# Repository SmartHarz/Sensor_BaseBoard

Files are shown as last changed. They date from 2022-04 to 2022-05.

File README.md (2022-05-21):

# Bosch Sensortec BME688 Breadboard Adapter

A simplistic sensor base board for BME688 air quality sensor by Bosch Sensortec

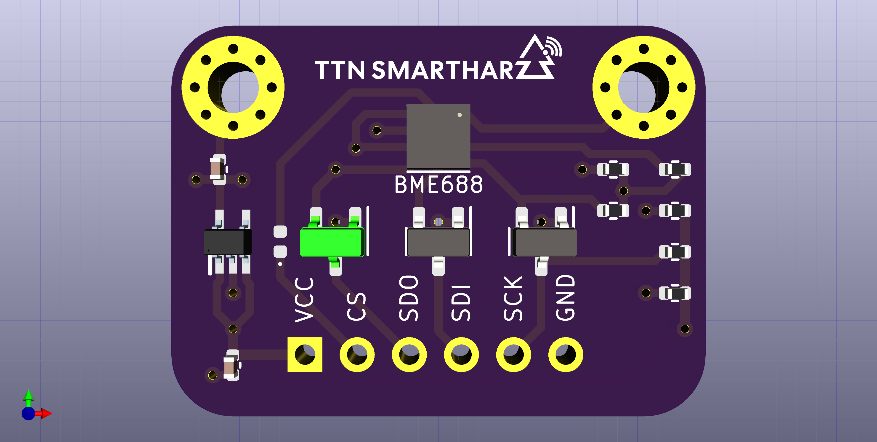
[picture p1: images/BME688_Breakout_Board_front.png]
Sensor board3D front view


The design allows for V<sub>CC</sub> and logic levels between 3V3 and 5V DC.

Due to the fact that the BME688 sensor features an LGA footprints with all pads below the sensor, manual soldering with a soldering iron is not possible for the sensor itself. All other parts can be soldered by hand, even though the 0402 components require a steady hand. Either way reflow soldering makes life a lot easier, if you keep the airflow low enough to not blow away your components. :wink:

The project folder [panel](/Sensor_BaseBoard/panel/) contains a panelized version as well
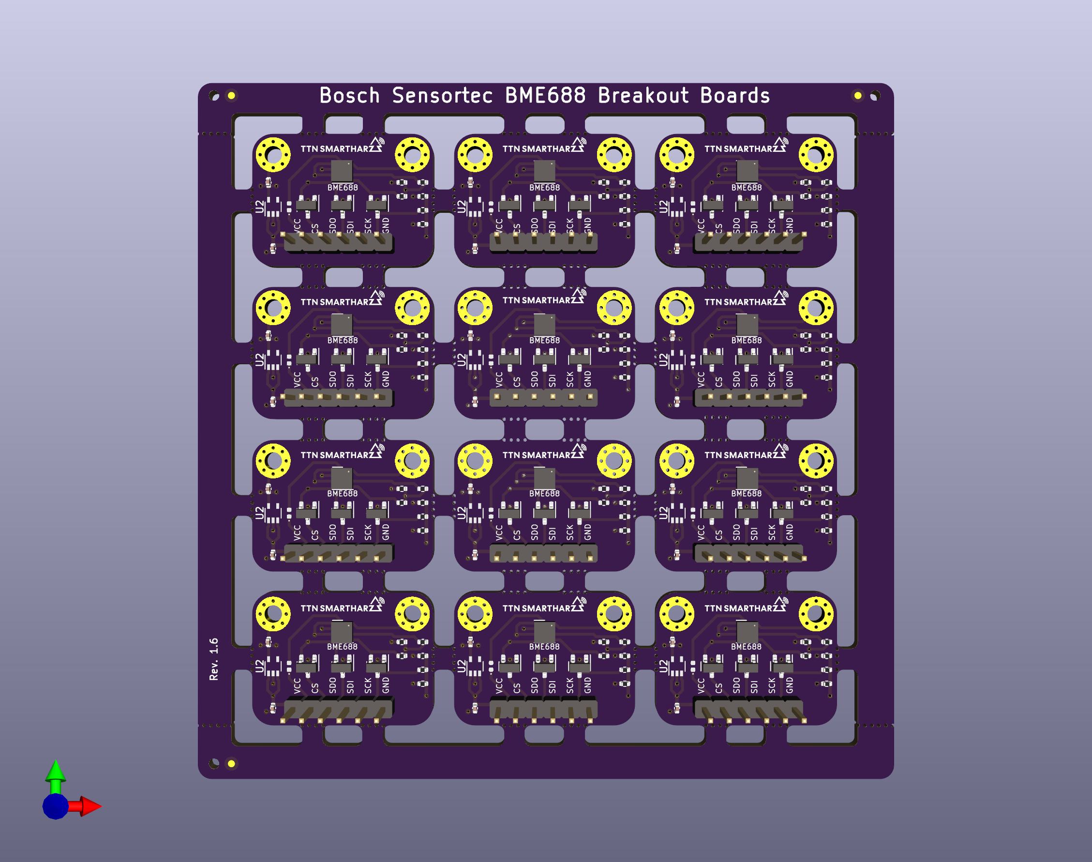
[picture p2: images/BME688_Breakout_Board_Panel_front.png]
Sensor board panel - front


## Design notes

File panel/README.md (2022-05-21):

# Bosch Sensortec BMEx80 Breadboard Adapter

This folder contains the [KiCAD](https://www.kicad.org/) project for a panelized version of the adapter.
The initial panel was generated using the kikit extension for KiCAD and afterwards cleaned up.

Panel 3D front
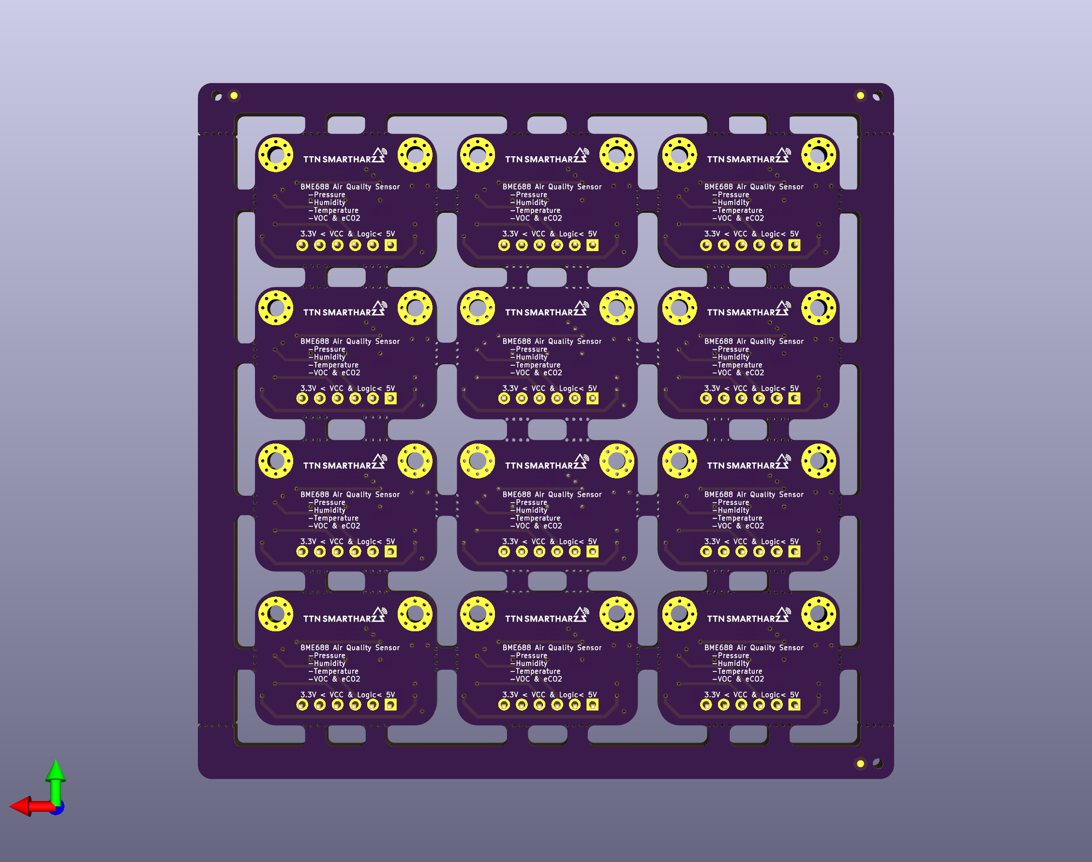
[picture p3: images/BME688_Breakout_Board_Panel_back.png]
Panel 3D back


As I prefer the look and feel I went with ENIG for manufacturing, but HASL lead free is of course perfectly fine as well.

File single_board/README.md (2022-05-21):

# Bosch Sensortec BMEx80 Breadboard Adapter

This folder contains the [KiCAD](https://www.kicad.org/) project for the single adapter.

## Schematic

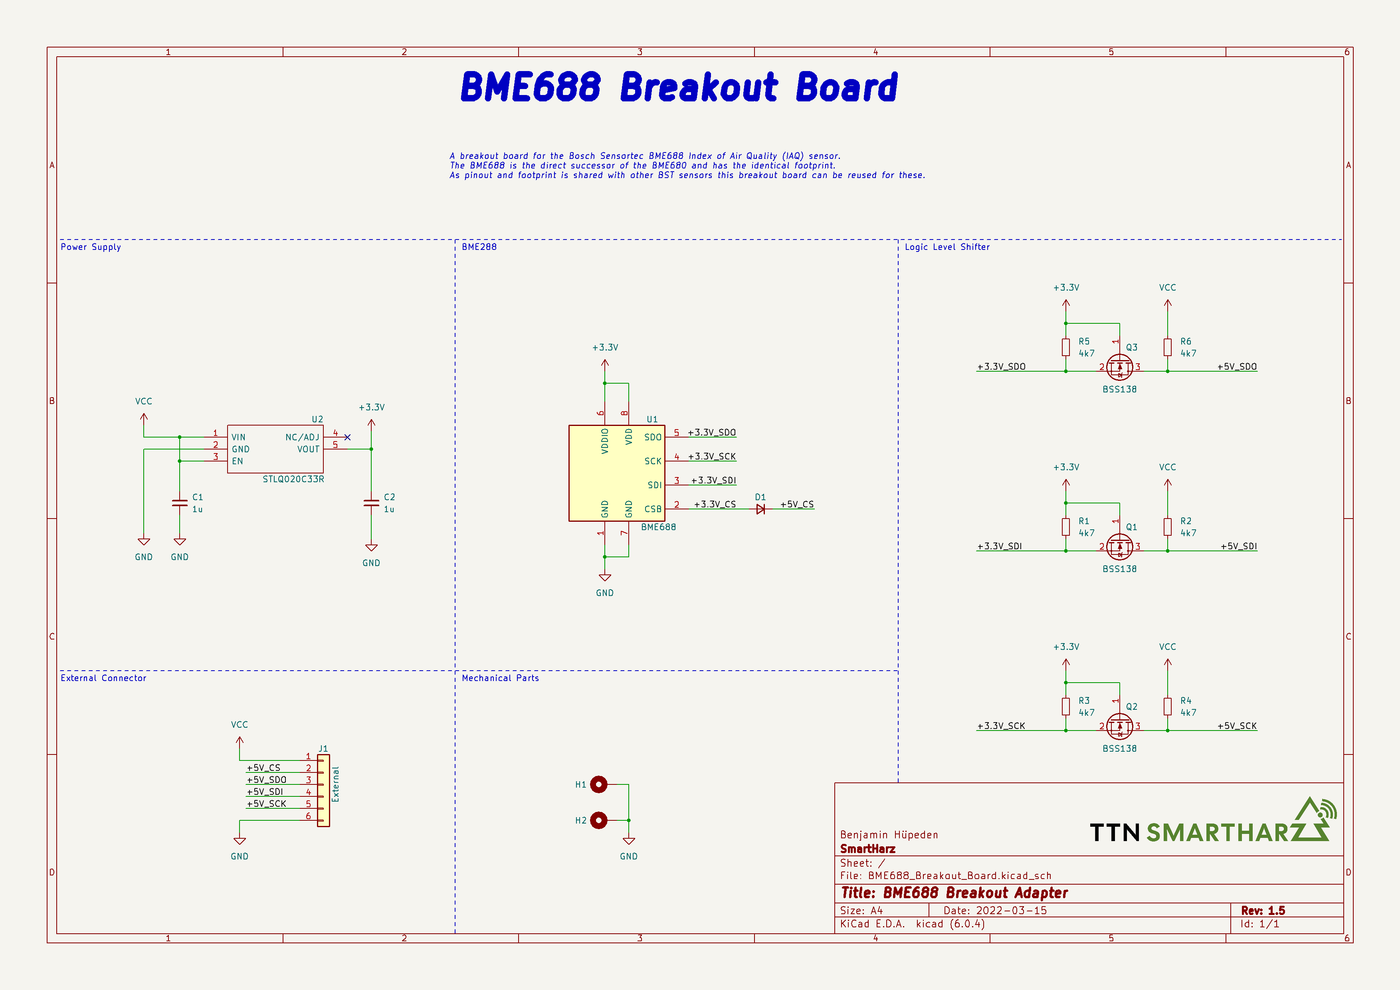
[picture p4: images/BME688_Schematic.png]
Adapter schematic

PDF of the schematic is available [here](BME688_Breakout_Board_Schematic.pdf).

## Layout

Adapter layout front
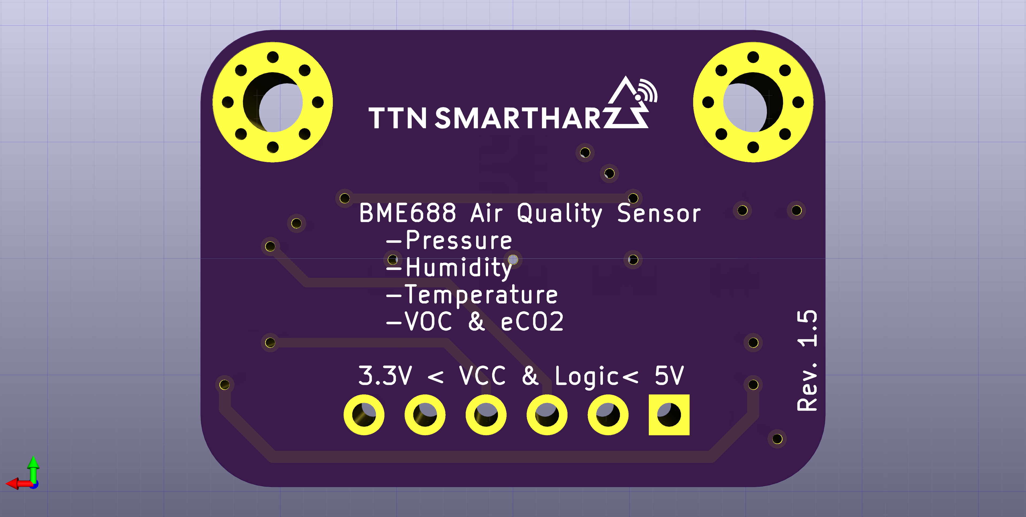
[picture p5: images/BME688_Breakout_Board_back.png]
Adapter layout back


As 4 layer boards nowadays are available at a similar price as 2 layer boards, I went for 4 layers, with dedicated GND and 3V3 planes in the middle.

A PDF of the layout is available [here](BME688_Breakout_Board_SingleLayers.pdf)(single page per layer) and [here](BME688_Breakout_Board_Condensed.pdf)(all layers condensed).

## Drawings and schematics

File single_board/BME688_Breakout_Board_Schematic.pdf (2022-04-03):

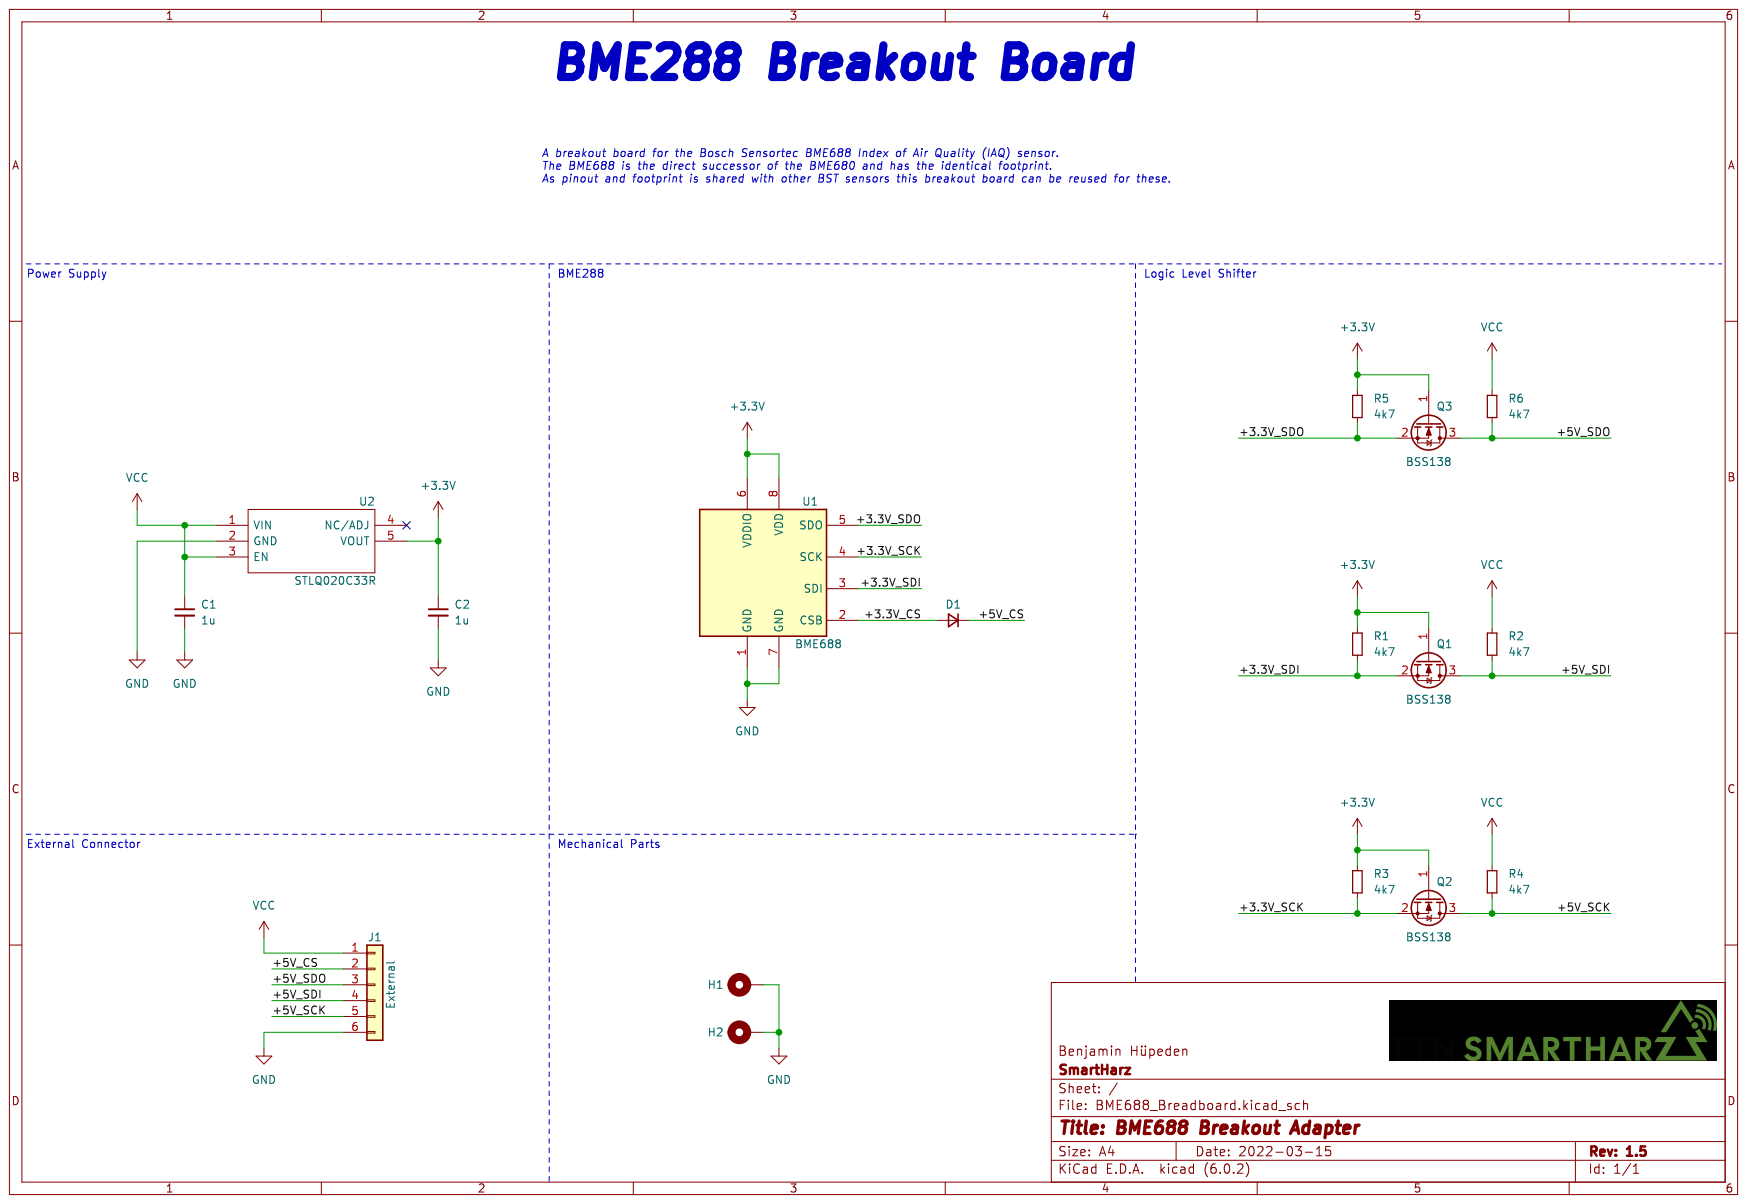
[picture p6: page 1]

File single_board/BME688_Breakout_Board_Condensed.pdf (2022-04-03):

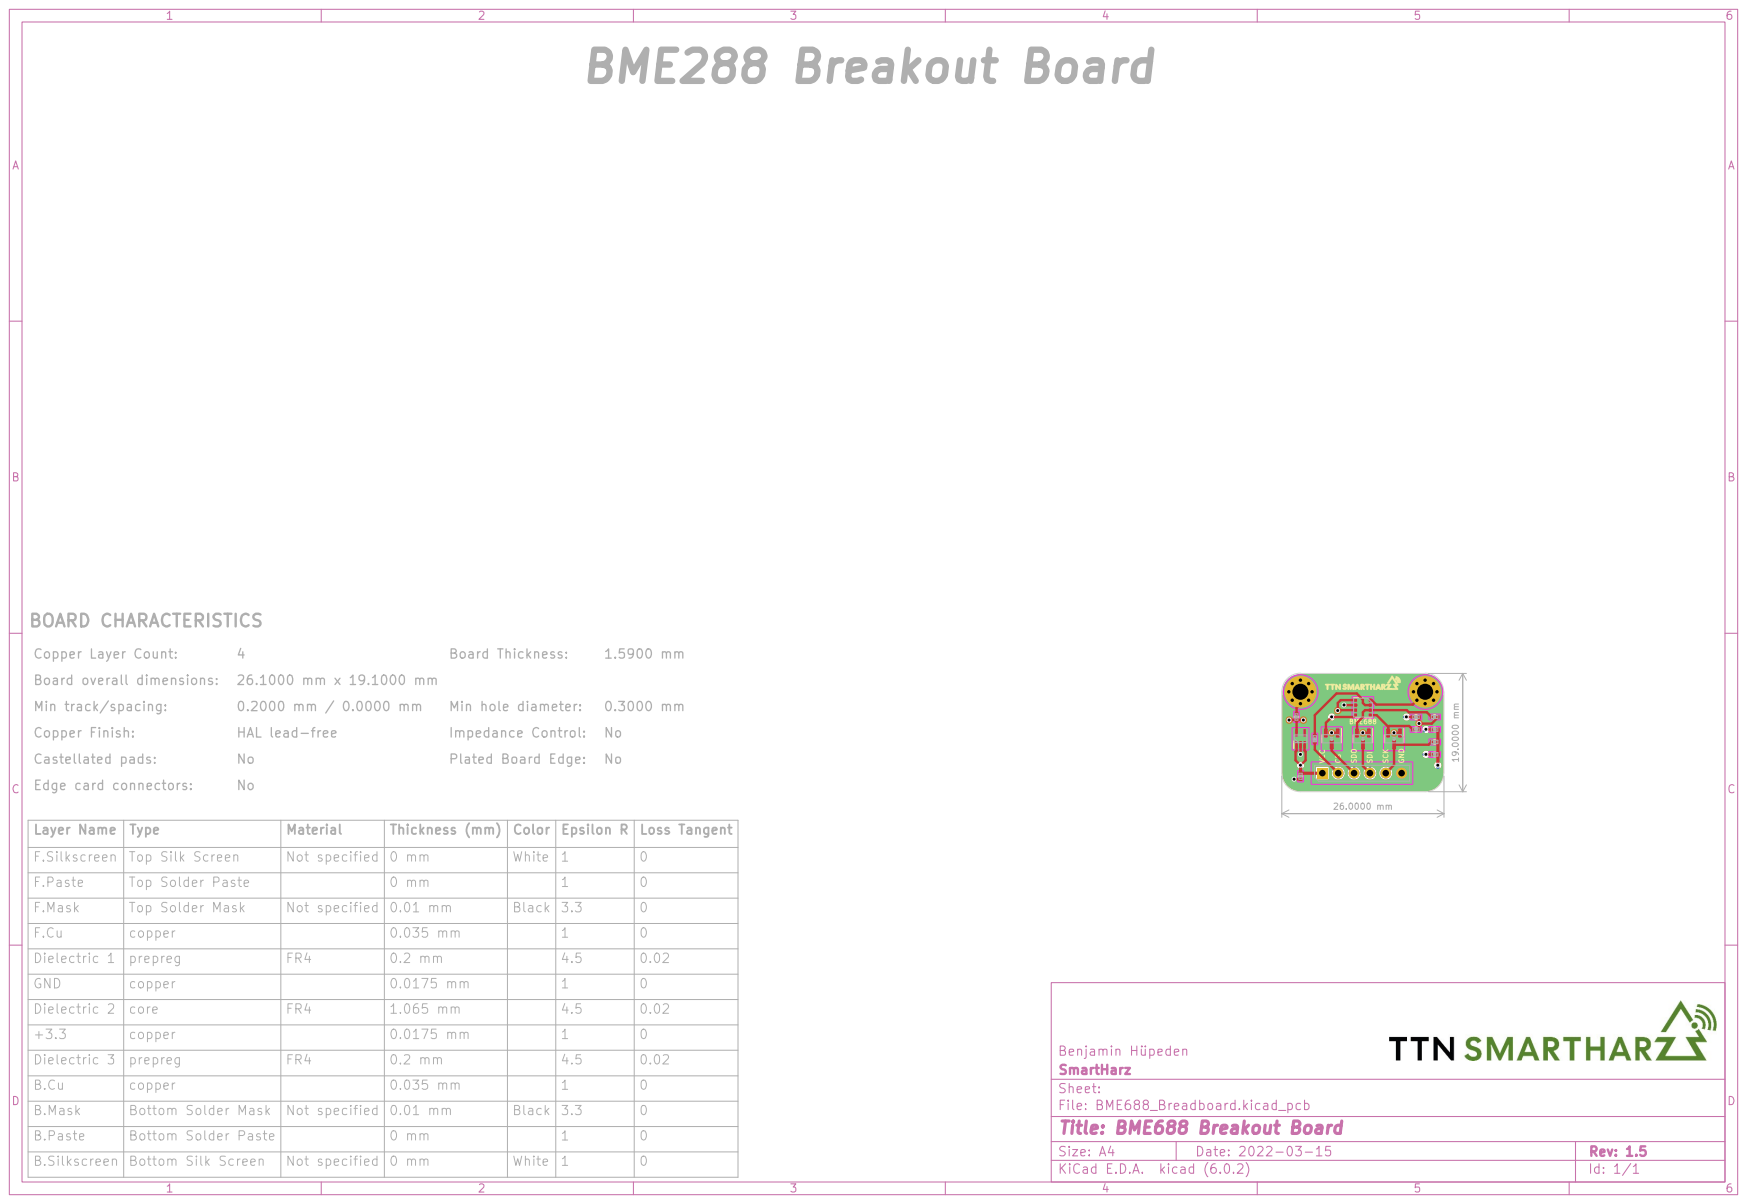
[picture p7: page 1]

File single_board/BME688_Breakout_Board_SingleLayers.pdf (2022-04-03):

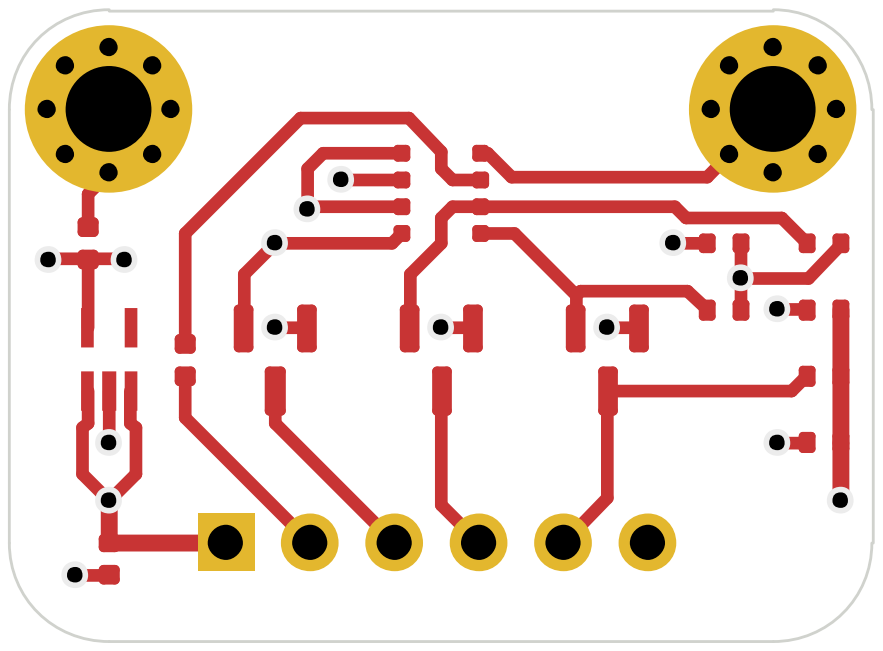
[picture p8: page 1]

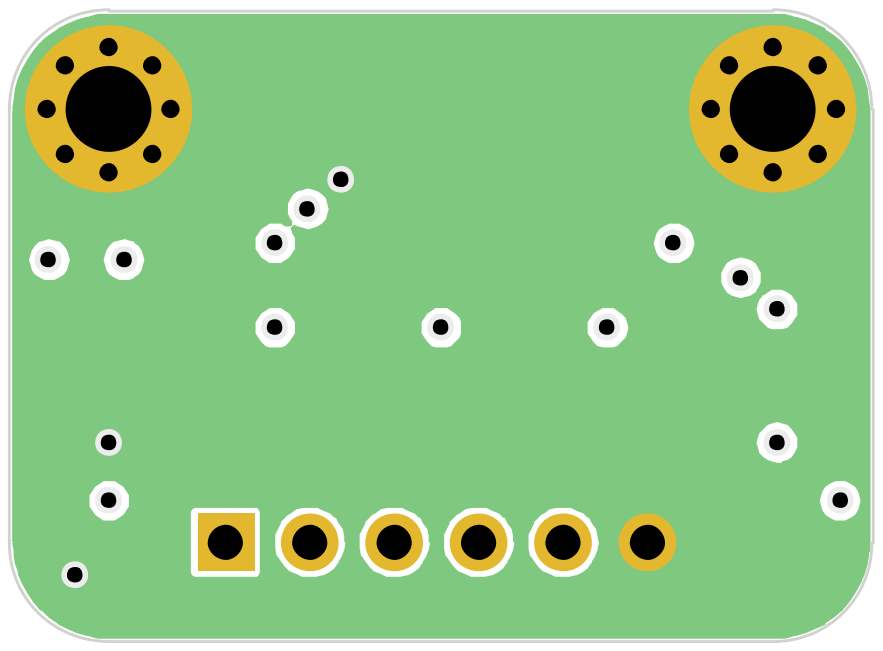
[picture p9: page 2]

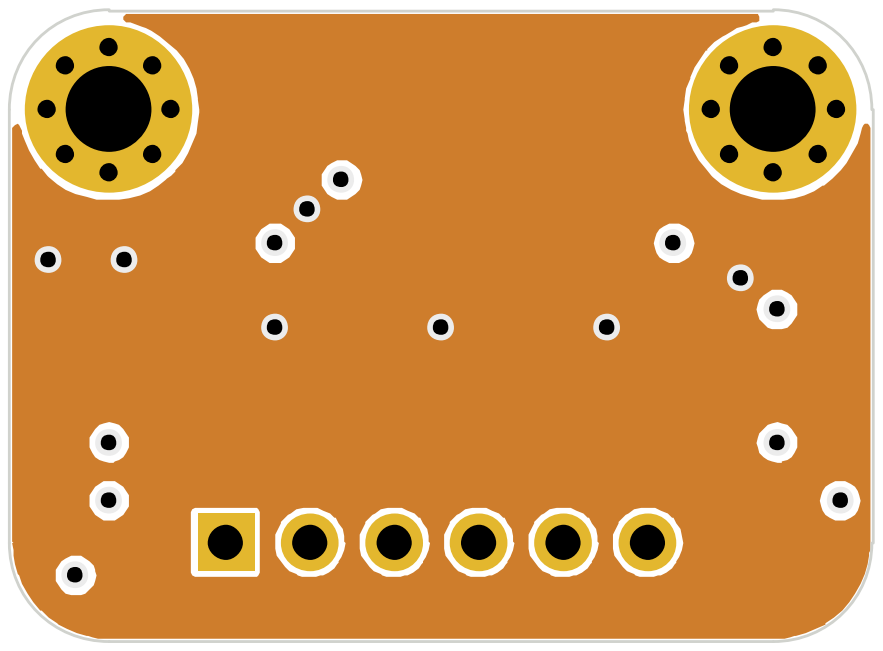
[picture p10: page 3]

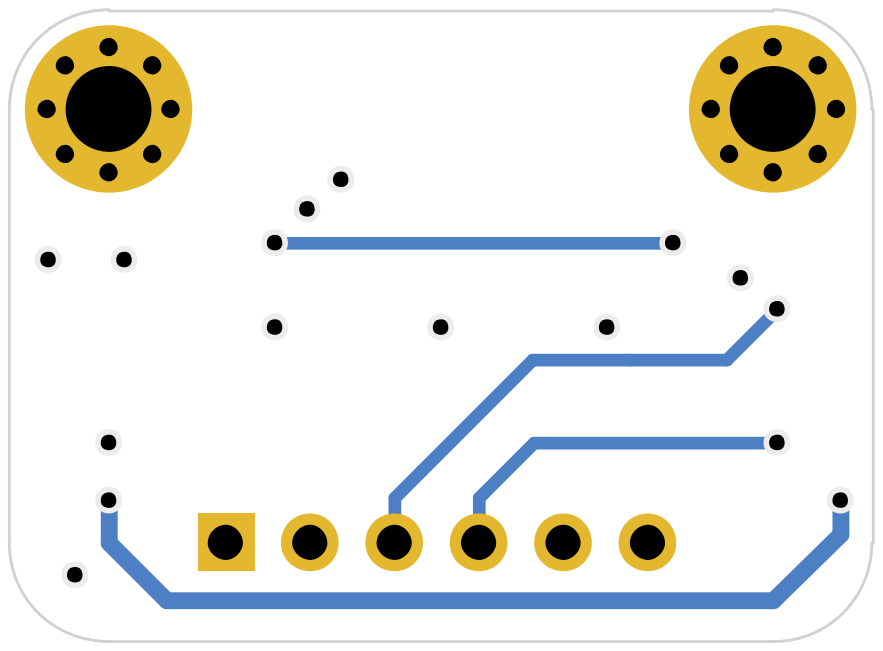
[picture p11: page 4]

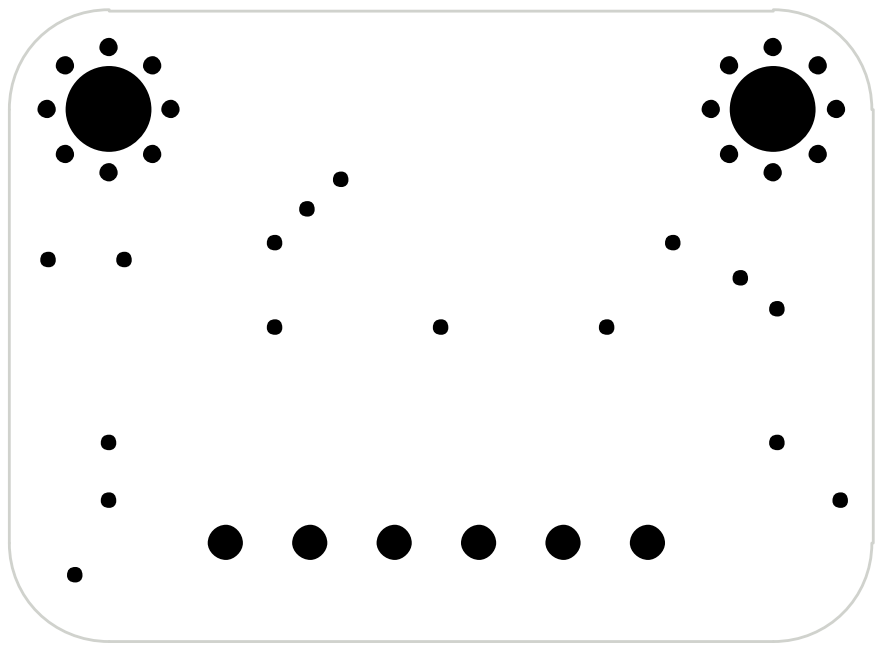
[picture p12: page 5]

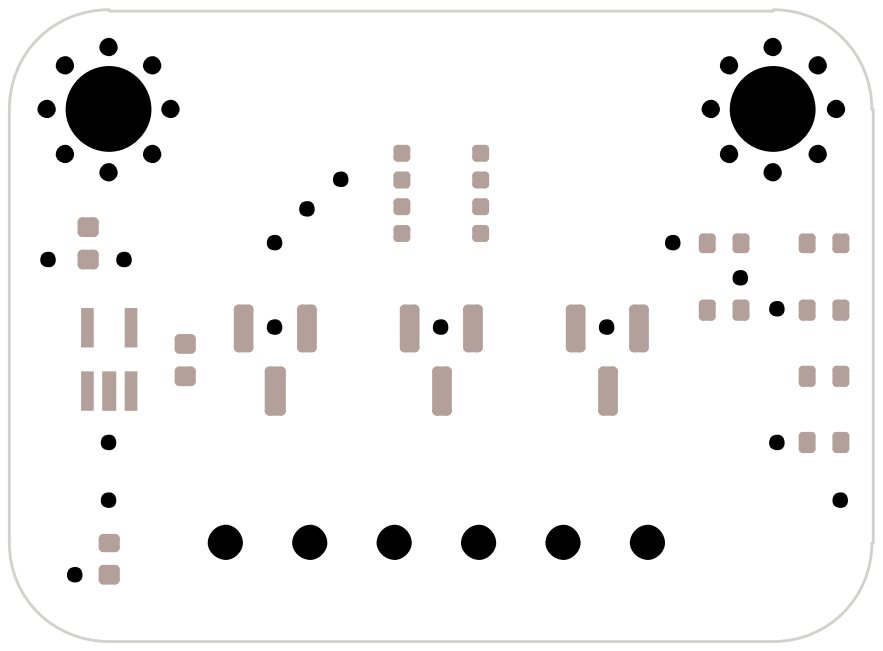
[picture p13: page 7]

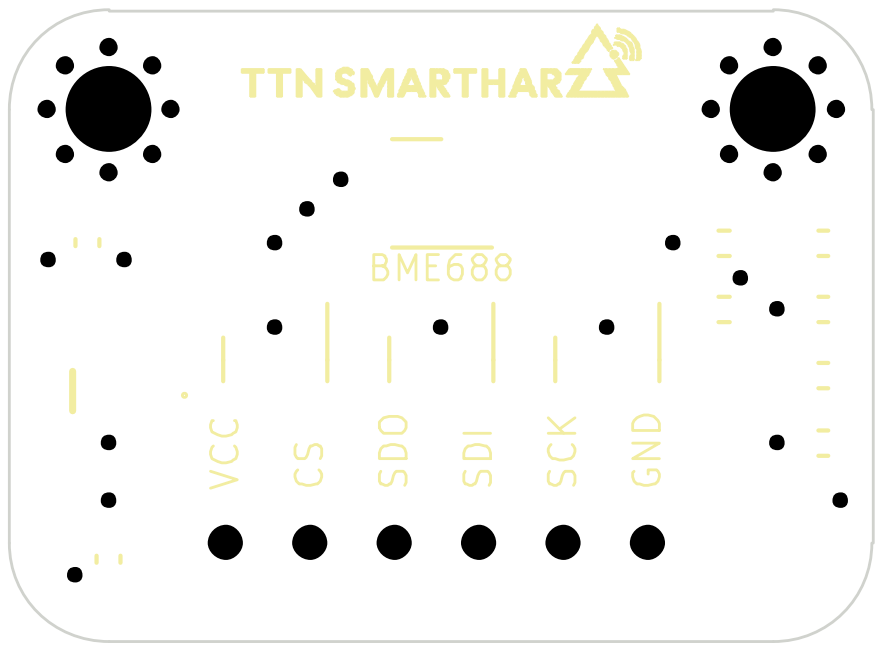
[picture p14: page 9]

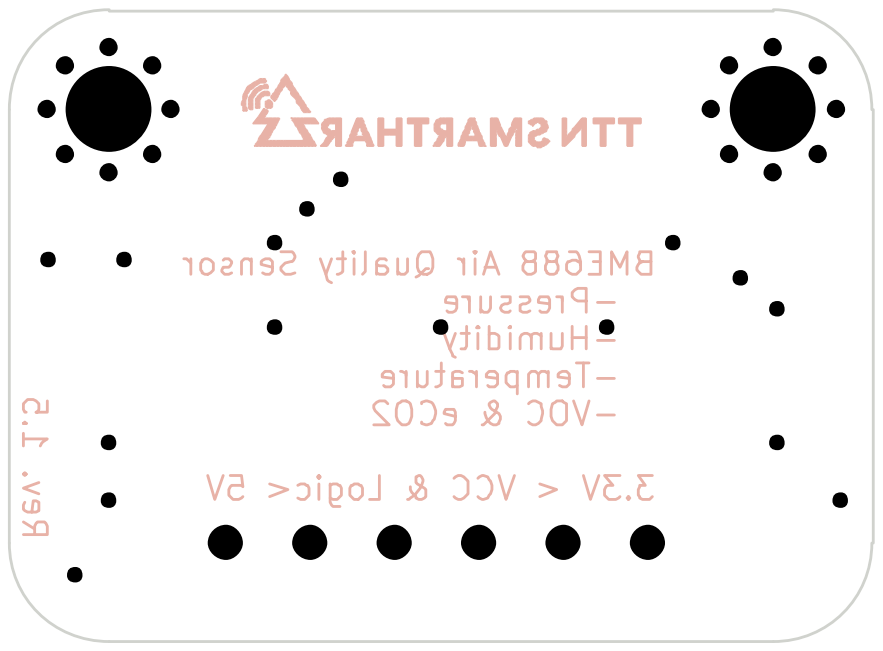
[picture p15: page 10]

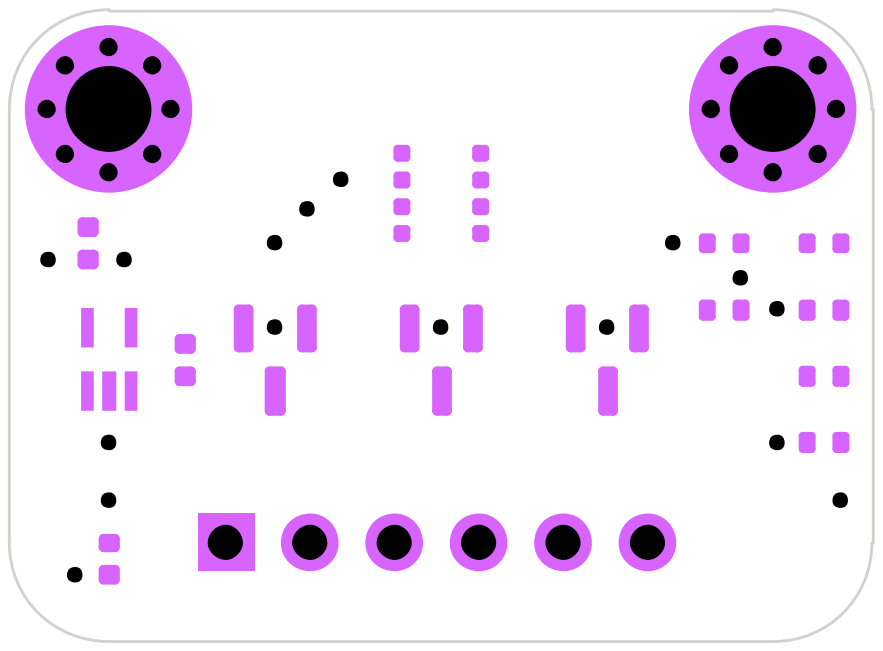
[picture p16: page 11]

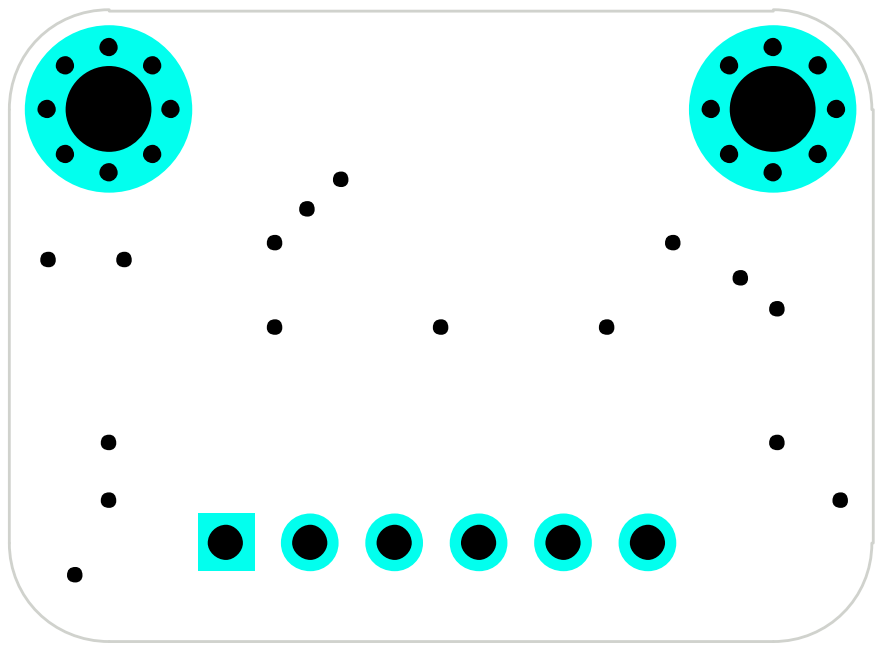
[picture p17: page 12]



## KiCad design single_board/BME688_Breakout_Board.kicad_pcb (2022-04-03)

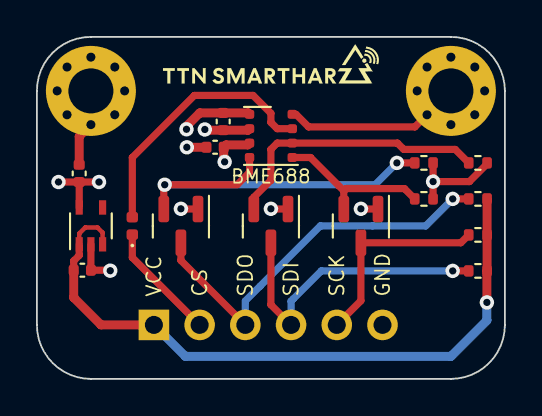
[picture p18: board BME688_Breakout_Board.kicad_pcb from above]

Board: 4 copper layers, 26.0 x 19.0 mm, 19 parts (0 on the bottom side), 11 nets.

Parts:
C1, C2: 1u; C_0402_1005Metric
C3, C4: 100n; C_0402_1005Metric
D1: Diode; D_0402_1005Metric
H1, H2: MountingHole_Pad; MountingHole_2.5mm_Pad_Via
J1: External; PinHeader_1x06_P2.54mm_Vertical
Q1, Q2, Q3: BSS138; SOT-23
R1, R2, R3, R4, R5, R6: 4k7; R_0402_1005Metric
U1: BME688; Bosch_LGA-8_3x3mm_P0.8mm_ClockwisePinNumbering
U2: STLQ020C33R; SOT323-5L

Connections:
+3V3: C2.1, C3.1, C4.1, Q1.1 (G), Q2.1 (G), Q3.1 (G), R1.1, R3.1, R5.1, U1.6 (VDDIO), U1.8 (VDD), U2.5 (VOUT)
/+3.3V_CS: D1.2 (A), U1.2 (CSB)
/+3.3V_SCK: Q2.2 (S), R3.2, U1.4 (SCK)
/+3.3V_SDI: Q1.2 (S), R1.2, U1.3 (SDI)
/+3.3V_SDO: Q3.2 (S), R5.2, U1.5 (SDO)
/+5V_CS: D1.1 (K), J1.2
/+5V_SCK: J1.5, Q2.3 (D), R4.2
/+5V_SDI: J1.4, Q1.3 (D), R2.2
/+5V_SDO: J1.3, Q3.3 (D), R6.2
GND: C1.2, C2.2, C3.2, C4.2, H1.1, H2.1, J1.6, U1.1 (GND), U1.7 (GND), U2.2 (GND)
VCC: C1.1, J1.1, R2.1, R4.1, R6.1, U2.1 (VIN), U2.3 (EN)
